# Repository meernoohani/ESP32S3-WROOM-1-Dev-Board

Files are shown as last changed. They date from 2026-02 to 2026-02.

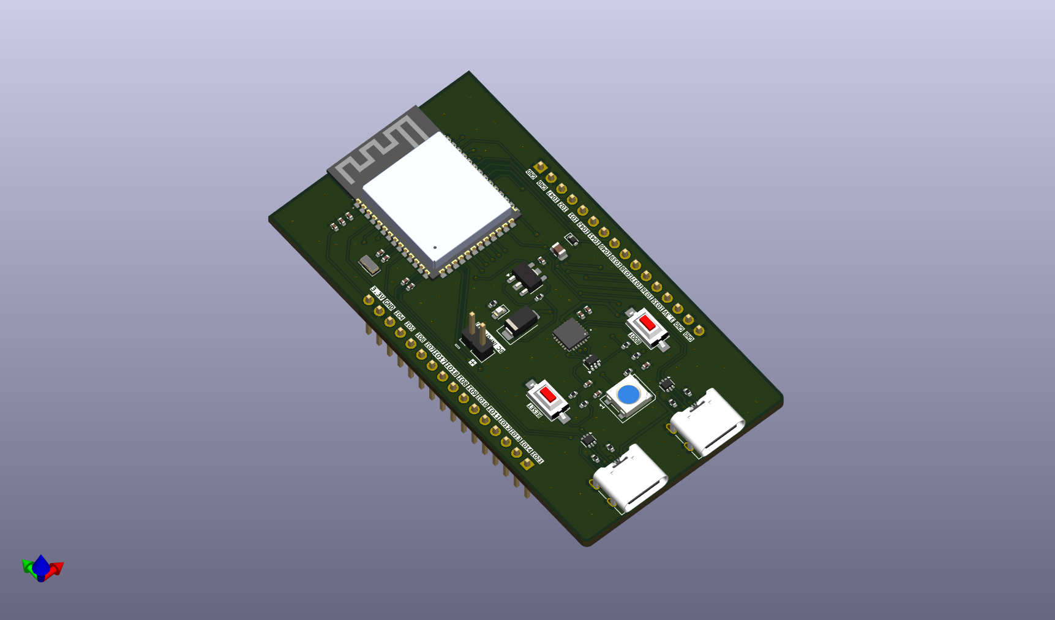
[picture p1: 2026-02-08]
Images/3D_View.png

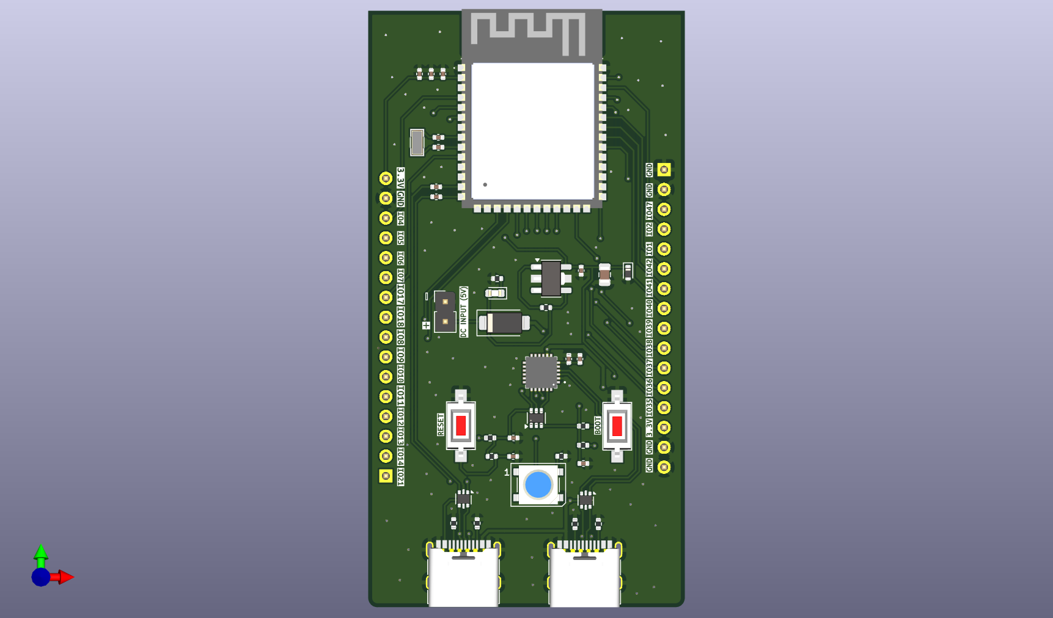
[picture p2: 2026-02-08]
Images/3D_View_front.png

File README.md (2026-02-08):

# ESP32-S3-N16R8 Custom Dev Board

A compact, high-performance development board powered by the **ESP32-S3-WROOM-1-N16R8** module, designed in **KiCad 9.0**. This design focuses on maximizing I/O accessibility and providing dual USB-C functionality for both debugging and native USB applications.

## 🛠 Features
* **MCU:** ESP32-S3 (Dual-core @ 240MHz)
* **Memory:** 16MB Flash / 8MB Octal PSRAM (N16R8 variant)
* **Connectivity:**
    * **USB-C (UART):** Dedicated interface for programming and debugging.
    * **USB-C (Native):** Direct access to S3 USB OTG pins.
* **I/O:** Full breakout of all usable GPIOs to 0.1" (2.54mm) headers.
* **Design Tool:** KiCad 9.0

## ⚙️ Hardware Setup
To utilize the 16MB Flash and 8MB PSRAM in your IDE (Arduino/ESP-IDF), use the following settings:

| Setting | Value |
| :--- | :--- |
| **Board** | ESP32S3 Dev Module |
| **Flash Mode** | QIO |
| **Flash Size** | 16MB |
| **PSRAM** | OPI PSRAM |



## 📦 Production Files
This repository includes production-ready files optimized for manufacturing via **JLCPCB**, located in the `/JLCPCB BOM & Gerber Files` folder. This includes:
* Gerber Files
* Drill Files
* BOM (Bill of Materials)
* CPL (Component Placement List / Pick-and-Place)

---
*Note: This project is shared for reference and educational purposes.*

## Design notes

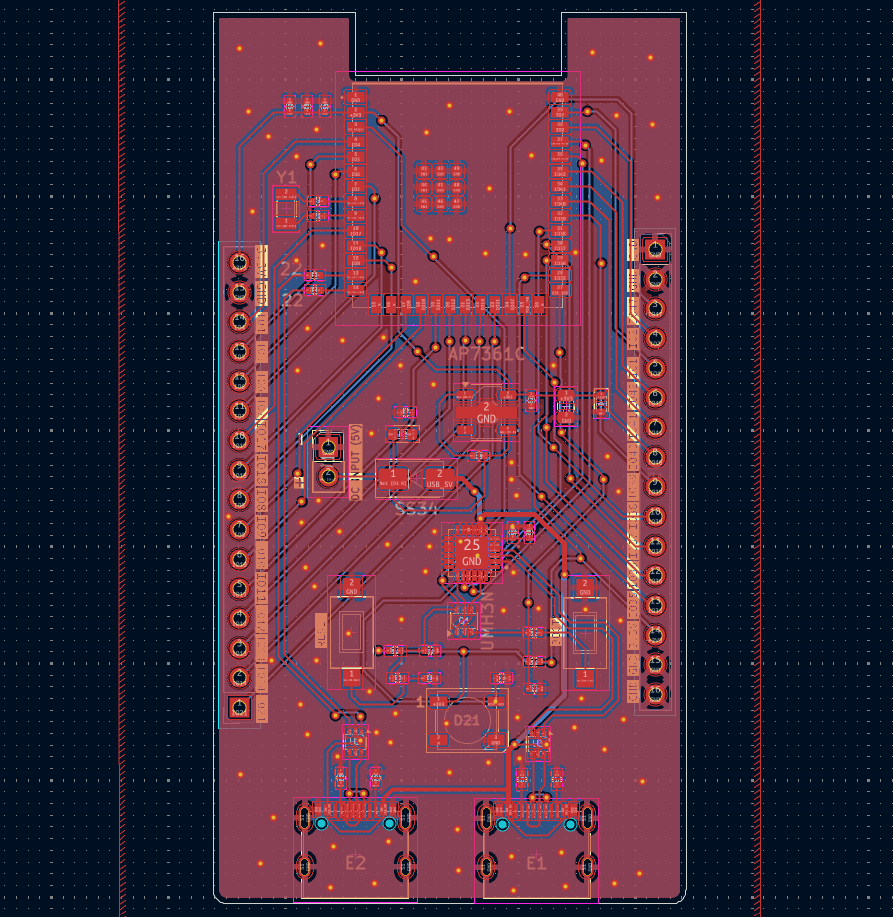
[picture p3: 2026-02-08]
Images/PCB_Layout_Front.png

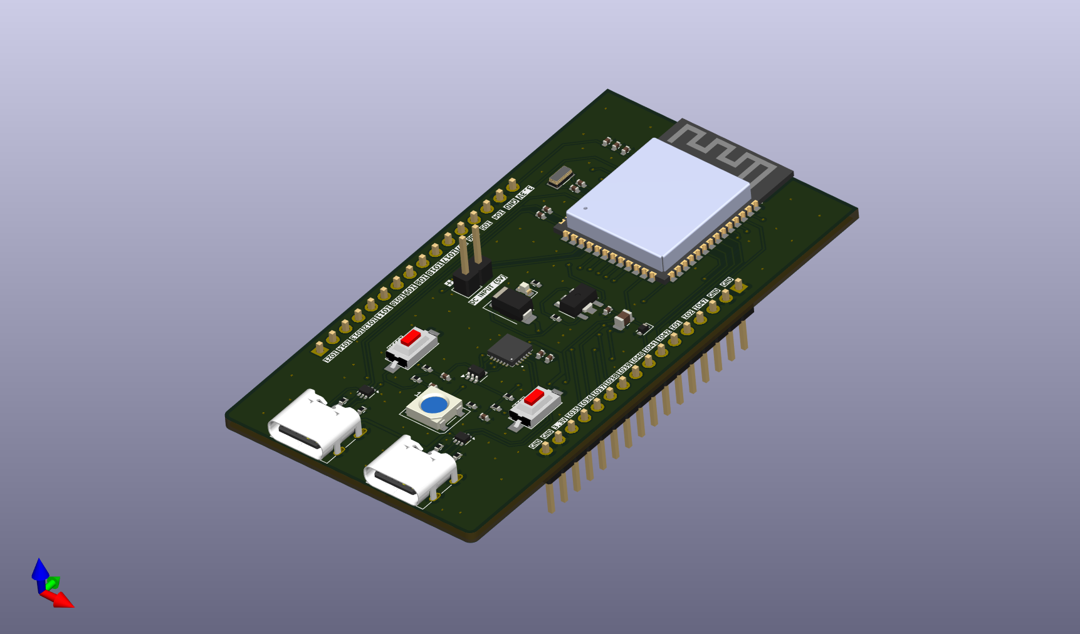
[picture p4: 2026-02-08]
Images/3D_View_2.png

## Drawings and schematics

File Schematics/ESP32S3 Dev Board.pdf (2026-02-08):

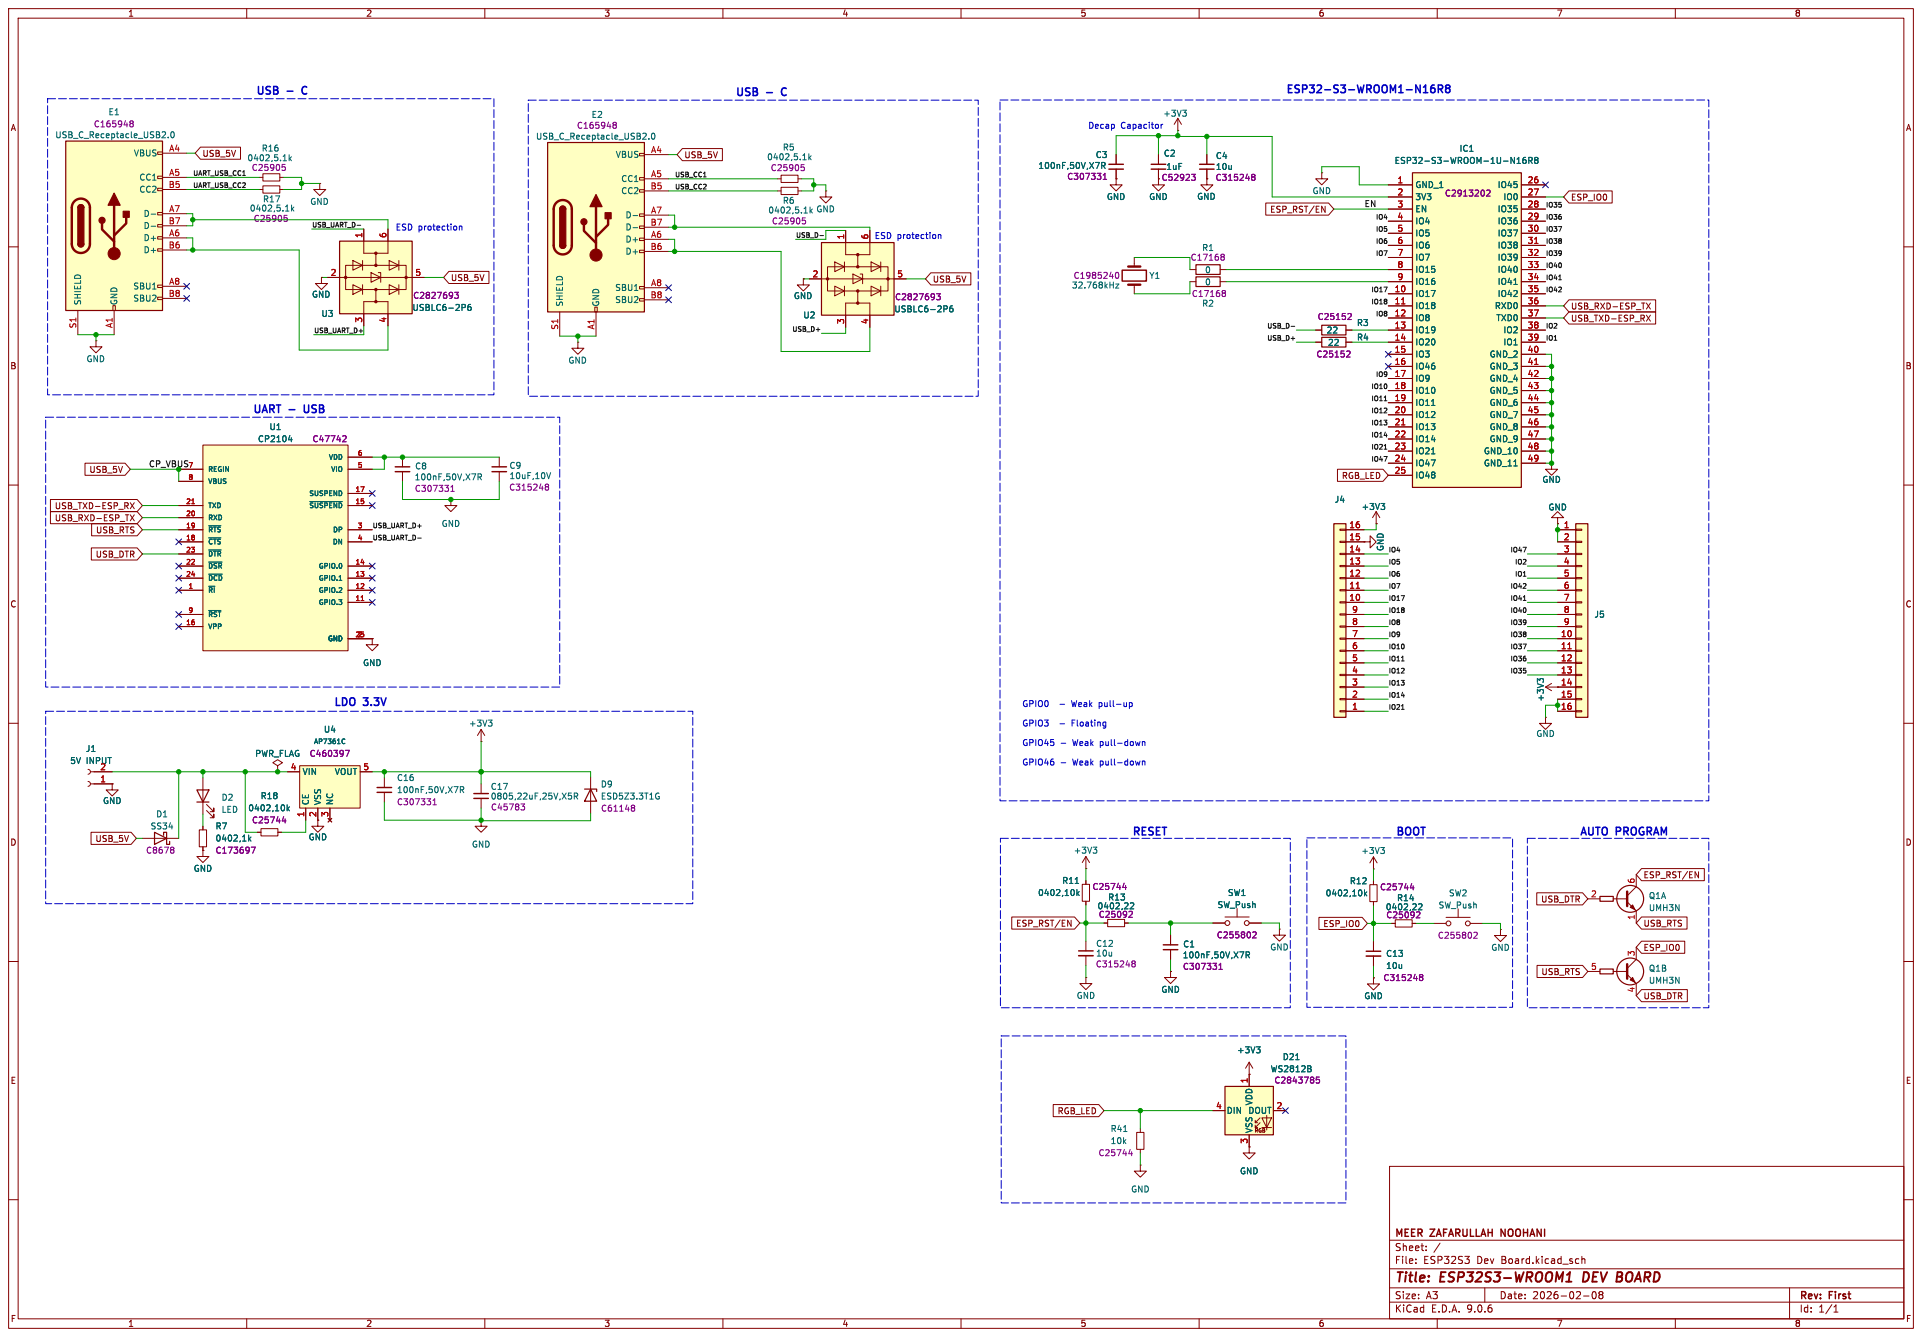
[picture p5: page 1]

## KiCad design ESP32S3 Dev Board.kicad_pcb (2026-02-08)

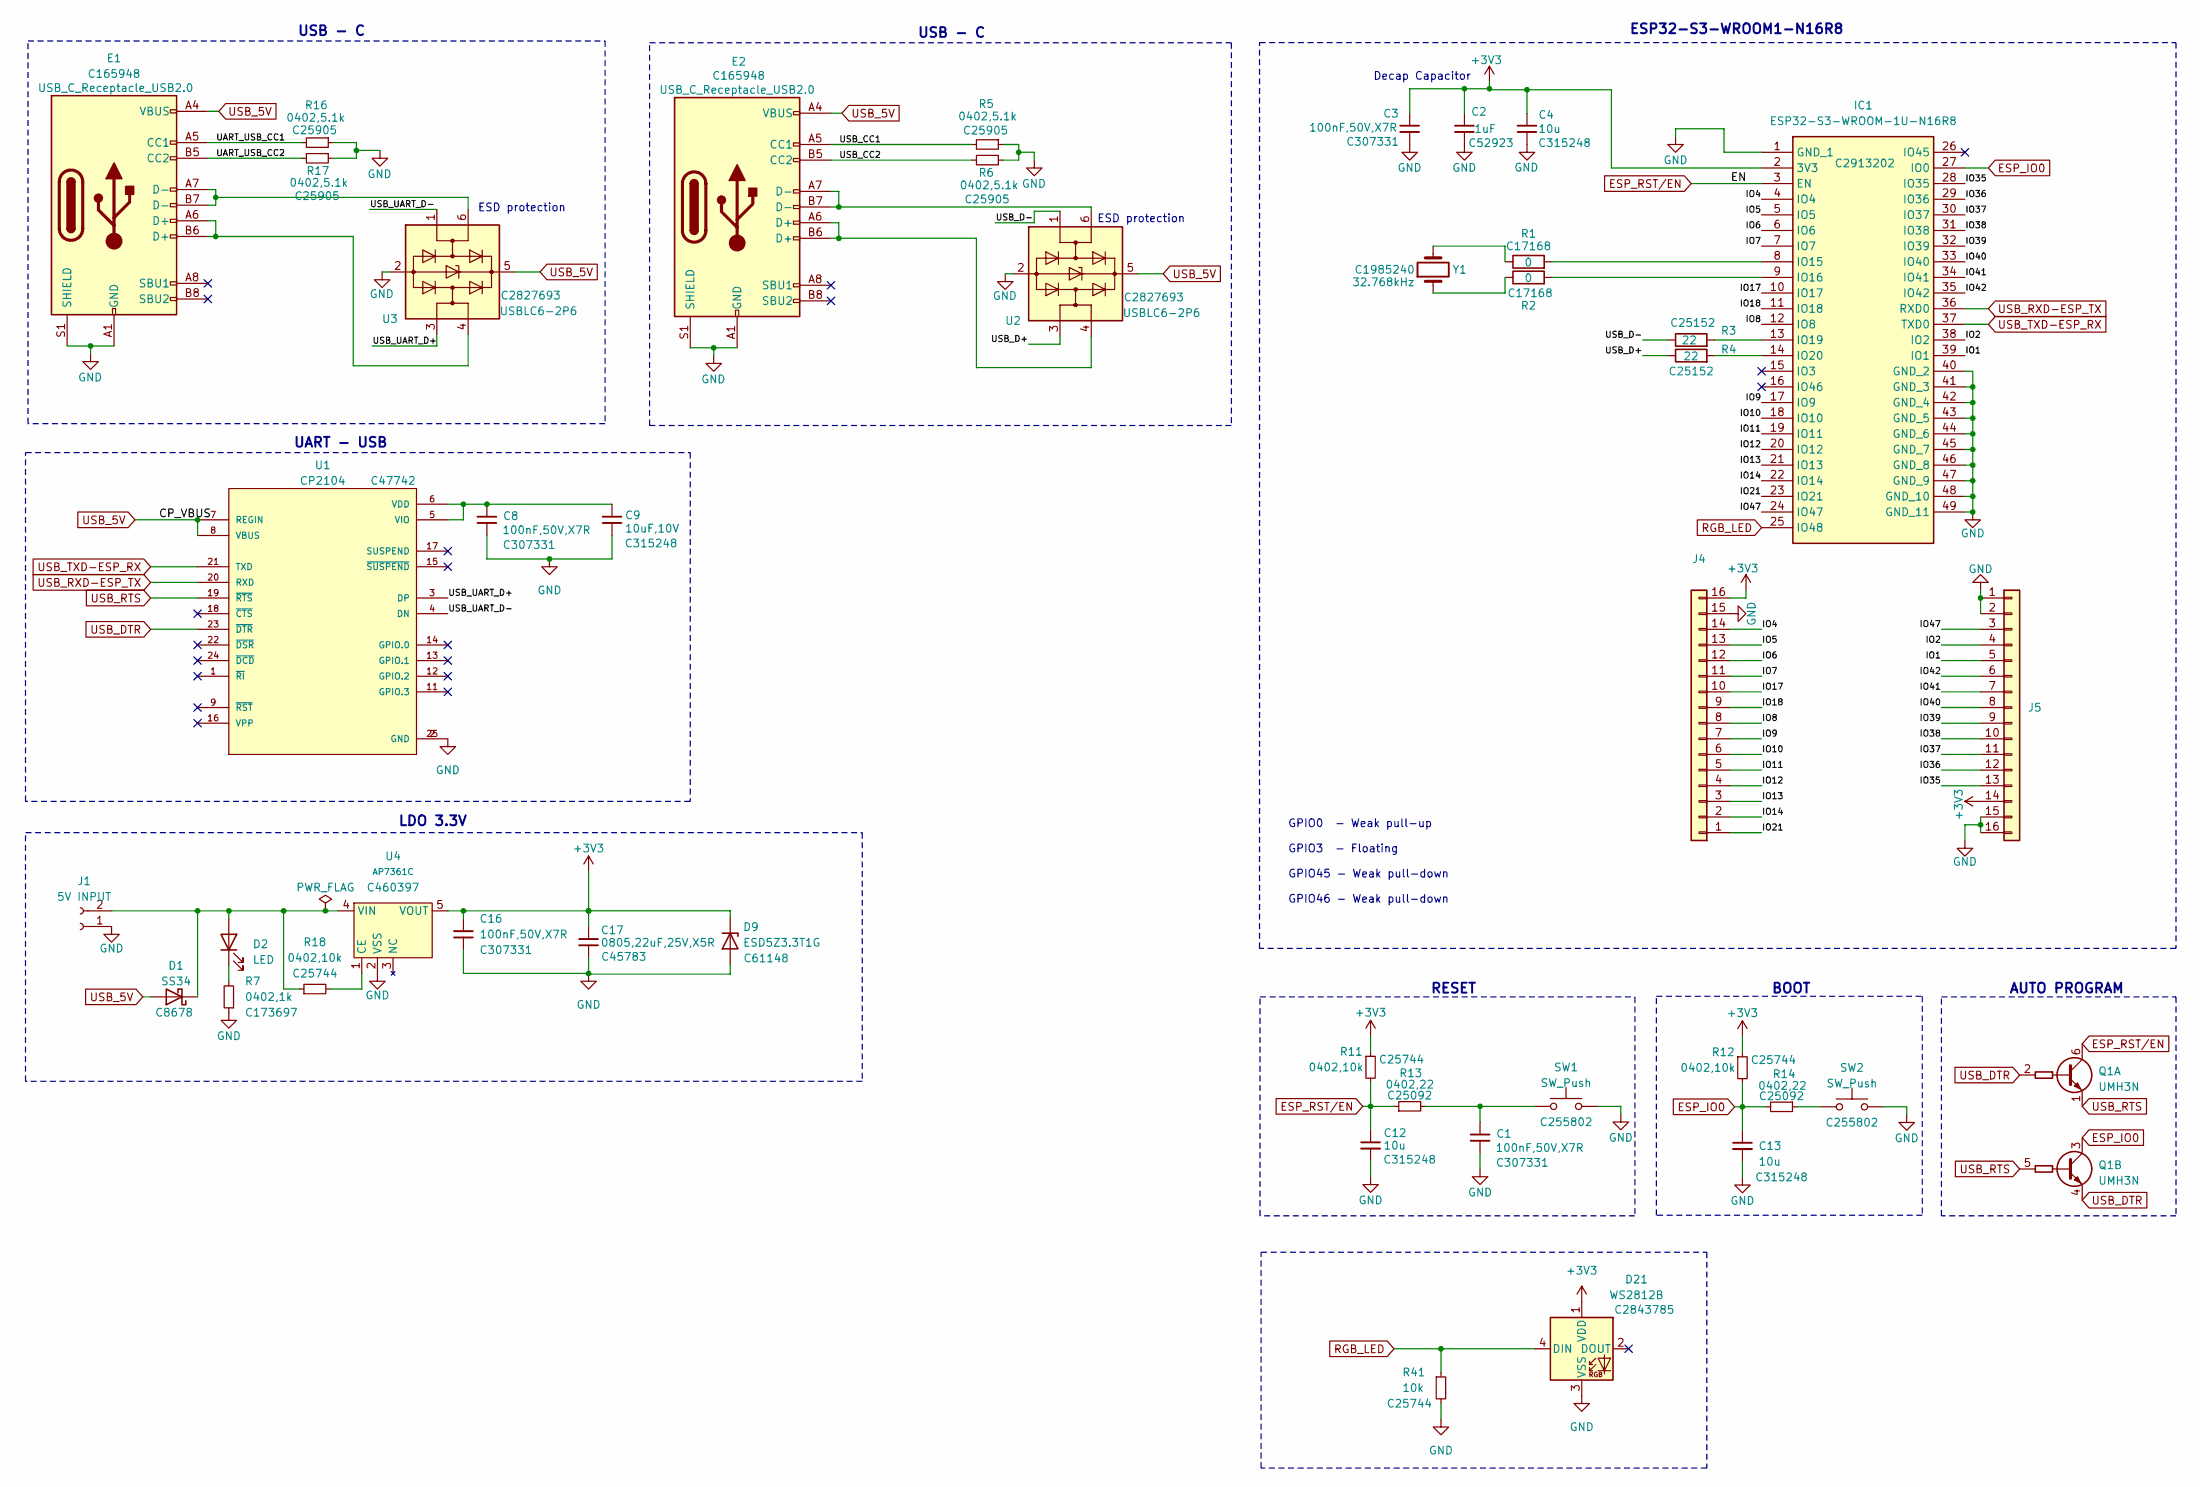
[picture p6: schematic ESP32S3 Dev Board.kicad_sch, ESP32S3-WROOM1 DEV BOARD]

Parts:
C1, C3, C8, C16: 100nF,50V,X7R; C_0402_1005Metric; MFGPN CL05B104KB54PNC; LCSC C307331
C2: 1uF; C_0402_1005Metric; MFGPN CL05A105KA5NQNC; LCSC C52923
C4: 10u; C_0402_1005Metric; MFGPN CL05B104KB54PNC; LCSC C315248
C9: 10uF,10V; C_0402_1005Metric; MFGPN CL05B104KB54PNC; LCSC C315248
C12, C13: 10u; C_0402_1005Metric; LCSC C315248
C17: 0805,22uF,25V,X5R; C_0805_2012Metric; MFGPN CL21A226MAQNNNE; LCSC C45783
D1: SS34; D_SMA; LCSC C8678
D2: LED; LED_0603_1608Metric
D9: ESD5Z3.3T1G; D_SOD-523; LCSC C61148
D21: WS2812B; LED_WS2812B_PLCC4_5.0x5.0mm_P3.2mm; LCSC C2843785
E1, E2: USB_C_Receptacle_USB2.0; USB_C; LCSC C165948
IC1: ESP32-S3-WROOM-1U-N16R8; ESP32S3WROOM1UN16R8; Mouser Part Number 356-ESP32S3WM1UN16R8
J1: 5V INPUT; PinHeader_1x02_P2.54mm_Vertical
J4, J5: Conn_01x16; PinHeader_1x16_P2.54mm_Vertical
Q1: UMH3N; SOT-363_SC-70-6; LCSC C62892
R1, R2: 0; C_0402_1005Metric; LCSC C17168
R3, R4: 22; C_0402_1005Metric; LCSC C25152
R5, R6, R16, R17: 0402,5.1k; R_0402_1005Metric; MFGPN 0402WGF5101TCE; LCSC C25905
R7: 0402,1k; R_0402_1005Metric; MFGPN 0402WGF1002TCE; LCSC C173697
R11, R12, R18: 0402,10k; R_0402_1005Metric; MFGPN 0402WGF1002TCE; LCSC C25744
R13, R14: 0402,22; R_0402_1005Metric; MFGPN 0402WGF220JTCE; LCSC C25092
R41: 10k; R_0402_1005Metric; LCSC C25744
SW1, SW2: SW_Push; SW_SPST_CK_RS282G05A3; LCSC C255802
U1: CP2104; CP2104_QFN50P400X400X80-25N; PARTREV 1.0; LCSC C47742
U2, U3: USBLC6-2P6; SOT-666; LCSC C2827693
U4: AP7361C; SOT-89-5; LCSC C460397
Y1: 32.768kHz; Crystal_SMD_3215-2Pin_3.2x1.5mm; LCSC C1985240

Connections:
+3V3: C2.1, C3.1, C4.1, C16.1, C17.1, D9.1 (K), D21.1 (VDD), IC1.2 (3V3), J4.16, J5.14, R11.1, R12.1, U4.5 (VOUT)
/IO1: IC1.39 (IO1), J5.5
/IO2: IC1.38 (IO2), J5.4
/IO4: IC1.4 (IO4), J4.14
/IO5: IC1.5 (IO5), J4.13
/IO6: IC1.6 (IO6), J4.12
/IO7: IC1.7 (IO7), J4.11
/IO8: IC1.12 (IO8), J4.8
/IO9: IC1.17 (IO9), J4.7
/IO10: IC1.18 (IO10), J4.6
/IO11: IC1.19 (IO11), J4.5
/IO12: IC1.20 (IO12), J4.4
/IO13: IC1.21 (IO13), J4.3
/IO14: IC1.22 (IO14), J4.2
/IO17: IC1.10 (IO17), J4.10
/IO18: IC1.11 (IO18), J4.9
/IO21: IC1.23 (IO21), J4.1
/IO35: IC1.28 (IO35), J5.13
/IO36: IC1.29 (IO36), J5.12
/IO37: IC1.30 (IO37), J5.11
/IO38: IC1.31 (IO38), J5.10
/IO39: IC1.32 (IO39), J5.9
/IO40: IC1.33 (IO40), J5.8
/IO41: IC1.34 (IO41), J5.7
/IO42: IC1.35 (IO42), J5.6
/IO47: IC1.24 (IO47), J5.3
/UART_USB_CC1: E1.A5 (CC1), R16.2
/UART_USB_CC2: E1.B5 (CC2), R17.2
/USB_CC1: E2.A5 (CC1), R5.2
/USB_CC2: E2.B5 (CC2), R6.2
/USB_D+: R4.1, U2.3 (I/O2)
/USB_D-: R3.1, U2.1 (I/O1)
/USB_UART_D+: U1.3 (DP), U3.3 (I/O2)
/USB_UART_D-: U1.4 (DN), U3.1 (I/O1)
ESP_IO0: C13.1, IC1.27 (IO0), Q1.3 (C2), R12.2, R14.2
ESP_RST/EN: C12.1, IC1.3 (EN), Q1.6 (C1), R11.2, R13.1
GND: C1.2, C2.2, C3.2, C4.2, C8.2, C9.2, C12.2, C13.2, C16.2, C17.2, D9.2 (A), D21.3 (VSS), E1.A1 (GND), E1.A12 (GND), E1.B1 (GND), E1.B12 (GND), E1.S1 (SHIELD), E2.A1 (GND), E2.A12 (GND), E2.B1 (GND), E2.B12 (GND), E2.S1 (SHIELD), IC1.1 (GND_1), IC1.40 (GND_2), IC1.41 (GND_3), IC1.42 (GND_4), IC1.43 (GND_5), IC1.44 (GND_6), IC1.45 (GND_7), IC1.46 (GND_8), IC1.47 (GND_9), IC1.48 (GND_10), IC1.49 (GND_11), J1.1, J4.15, J5.1, J5.2, J5.15, J5.16, R5.1, R6.1, R7.1, R16.1, R17.1, R41.2, SW1.2, SW2.2, U1.2 (GND), U1.25 (GND), U2.2 (GND), U3.2 (GND), U4.2 (VSS)
unnamed: C1.1, R13.2, SW1.1
unnamed: D1.1 (K), D2.2 (A), J1.2, R18.1, U4.4 (VIN)
unnamed: D2.1 (K), R7.2
unnamed: E1.A6 (D+), E1.B6 (D+), U3.4 (I/O2)
unnamed: E1.A7 (D-), E1.B7 (D-), U3.6 (I/O1)
unnamed: E2.A6 (D+), E2.B6 (D+), U2.4 (I/O2)
unnamed: E2.A7 (D-), E2.B7 (D-), U2.6 (I/O1)
unnamed: IC1.8 (IO15), R1.2
unnamed: IC1.9 (IO16), R2.2
unnamed: IC1.13 (IO19), R3.2
unnamed: IC1.14 (IO20), R4.2
unnamed: R1.1, Y1.2
unnamed: R2.1, Y1.1
unnamed: R14.1, SW2.1
unnamed: C8.1, C9.1, U1.5 (VIO), U1.6 (VDD)
unnamed: R18.2, U4.1 (CE)
RGB_LED: D21.4 (DIN), IC1.25 (IO48), R41.1
USB_5V: D1.2 (A), E1.A4 (VBUS), E1.A9 (VBUS), E1.B4 (VBUS), E1.B9 (VBUS), E2.A4 (VBUS), E2.A9 (VBUS), E2.B4 (VBUS), E2.B9 (VBUS), U1.7 (REGIN), U1.8 (VBUS), U2.5 (VBUS), U3.5 (VBUS)
USB_DTR: Q1.2 (B1), Q1.4 (E2), U1.23 (~DTR)
USB_RTS: Q1.1 (E1), Q1.5 (B2), U1.19 (~RTS)
USB_RXD-ESP_TX: IC1.36 (RXD0), U1.20 (RXD)
USB_TXD-ESP_RX: IC1.37 (TXD0), U1.21 (TXD)

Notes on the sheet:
BOOT
GPIO0 - Weak pull-up GPIO3 - Floating GPIO45 - Weak pull-down GPIO46 - Weak pull-down
Decap Capacitor
LDO 3.3V
USB - C
ESD protection
RESET
UART - USB
ESP32-S3-WROOM1-N16R8
AUTO PROGRAM

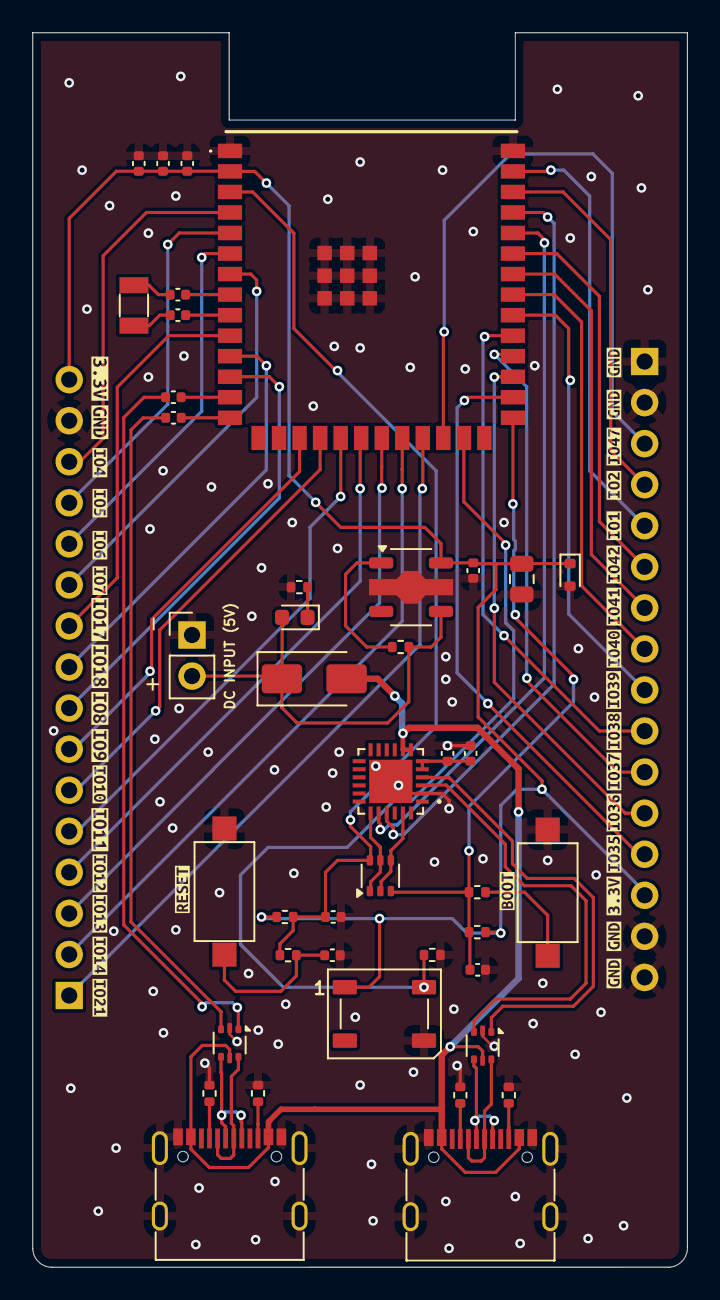
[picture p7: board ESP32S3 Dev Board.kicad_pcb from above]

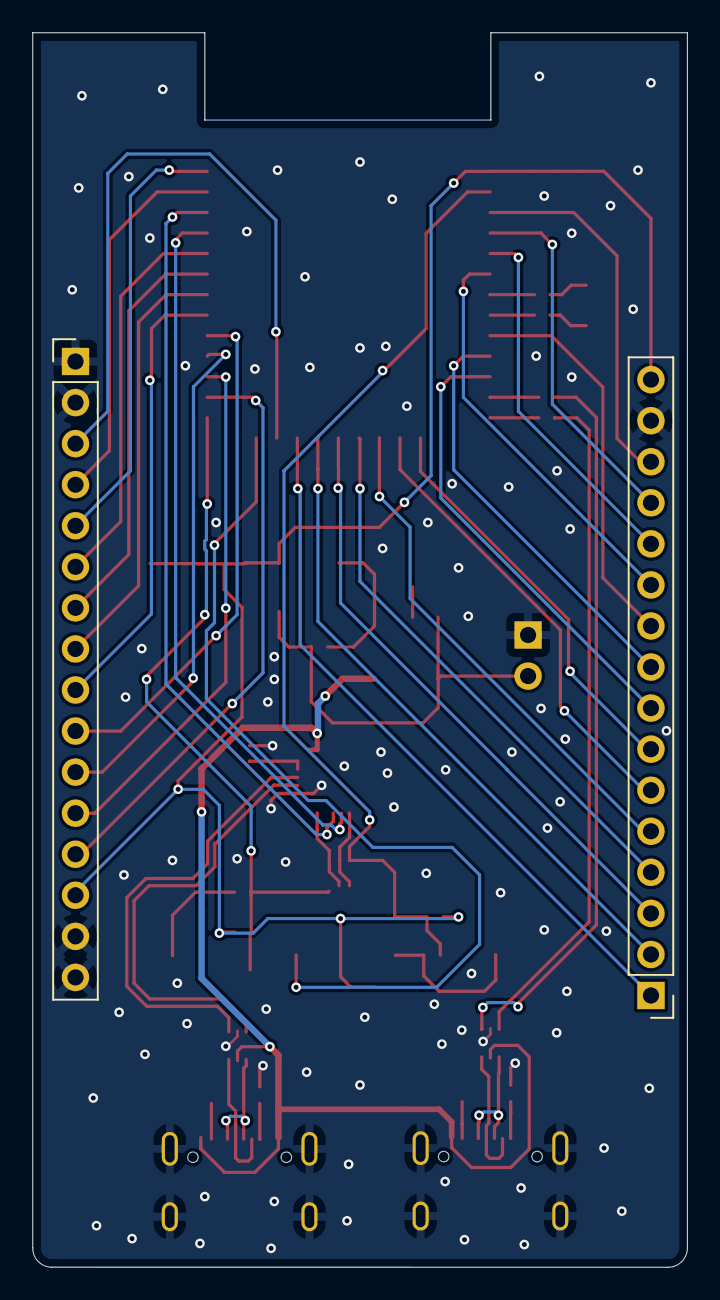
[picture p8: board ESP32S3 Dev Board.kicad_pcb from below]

Board: 2 copper layers, 40.5 x 76.4 mm, 77 parts (2 on the bottom side), 59 nets.

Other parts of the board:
kibuzzard-6988DF0D: G***; kibuzzard-6988DF0D
kibuzzard-6988DF05: G***; kibuzzard-6988DF05
kibuzzard-6988DF41: G***; kibuzzard-6988DF41
kibuzzard-6988DF49: G***; kibuzzard-6988DF49
kibuzzard-6988DF59: G***; kibuzzard-6988DF59
kibuzzard-6988DF68: G***; kibuzzard-6988DF68
kibuzzard-6988DF80: G***; kibuzzard-6988DF80
kibuzzard-6988E0B4: G***; kibuzzard-6988E0B4
kibuzzard-6988E0BB: G***; kibuzzard-6988E0BB
kibuzzard-6988E02D: G***; kibuzzard-6988E02D
kibuzzard-6988E04D: G***; kibuzzard-6988E04D
kibuzzard-6988E09C: G***; kibuzzard-6988E09C
kibuzzard-6988E10C: G***; kibuzzard-6988E10C
kibuzzard-6988E12C: G***; kibuzzard-6988E12C
kibuzzard-6988E13F: G***; kibuzzard-6988E13F
kibuzzard-6988E14E: G***; kibuzzard-6988E14E
kibuzzard-6988E15C: G***; kibuzzard-6988E15C
kibuzzard-6988E16F: G***; kibuzzard-6988E16F
kibuzzard-6988E025: G***; kibuzzard-6988E025
kibuzzard-6988E039: G***; kibuzzard-6988E039
kibuzzard-6988E063: G***; kibuzzard-6988E063
kibuzzard-6988E091: G***; kibuzzard-6988E091
kibuzzard-6988E101: G***; kibuzzard-6988E101
kibuzzard-6988E107: G***; kibuzzard-6988E107
kibuzzard-6988E119: G***; kibuzzard-6988E119
kibuzzard-6988E120: G***; kibuzzard-6988E120
kibuzzard-6988E134: G***; kibuzzard-6988E134
kibuzzard-6988E146: G***; kibuzzard-6988E146
kibuzzard-6988E155: G***; kibuzzard-6988E155
kibuzzard-6988E162: G***; kibuzzard-6988E162
kibuzzard-6988E169: G***; kibuzzard-6988E169
kibuzzard-6988E176: G***; kibuzzard-6988E176
kibuzzard-6988EF1E: G***; kibuzzard-6988EF1E
kibuzzard-6988EF30: G***; kibuzzard-6988EF30
